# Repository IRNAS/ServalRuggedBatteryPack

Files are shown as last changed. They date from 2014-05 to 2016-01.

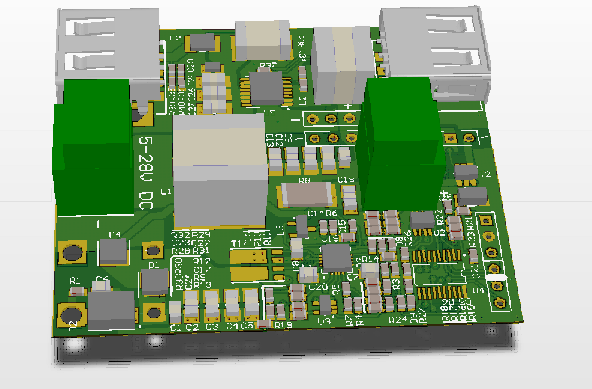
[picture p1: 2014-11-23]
electronics/V3/ServalRuggedBatteryPackV3.png

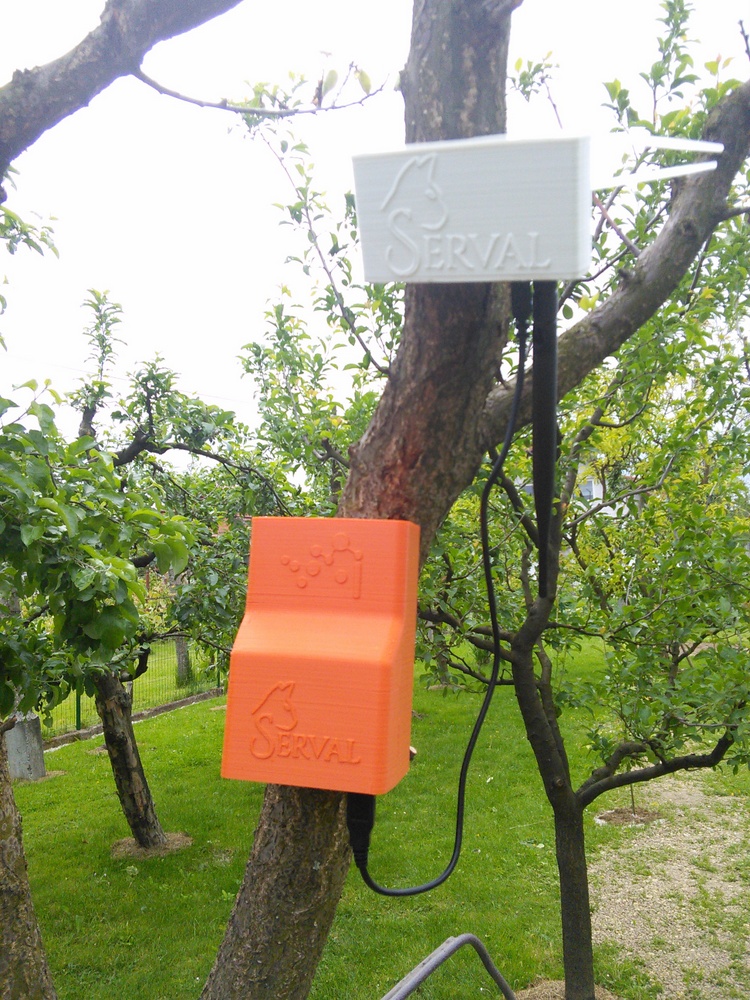
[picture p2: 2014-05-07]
photos/SRBP-Proto-4.jpg

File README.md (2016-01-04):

ServalRuggedBatteryPack
=======================

Serval Rugged Battery Pack is designed to be the universal battery supply system for wireless equipment in any situation. Let that be a rescue operation in New Zealand, every-day deployment in Africa or a remote location in Europe, all sharing the same lack of electrical power for communication equipment. Together with [Serval project](http://www.servalproject.org/)  we are creating an universal power solution for [Serval Mesh extender](http://developer.servalproject.org/dokuwiki/doku.php?id=content:meshextender:main_page)  and general use in community wireless networks.

## Early prototpe
Designed to house 2pcs LiFePO4 12Ah batteries and control electronics, developed in collaboration with [eCat](http://www.ecat.si/). It implements most of the described features, however supports only up to 1A charging current, making the usage of such a system with high capacity rather limited. Improvements are on the way.

Assembly parts:

ServalRuggedBatteryPack

Inside the 3D printed case:

ServalRuggedBatteryPack

In action with Serval Mesh Extender:

ServalRuggedBatteryPack
ServalRuggedBatteryPack

## Development goals
 * Supply power for the wireless device (5V USB or 12V)
 * Enough juice for days of operation
 * Charge it from just about anything
 * Make it hackable and reusable
 * Support real-time monitoring of the system
 
## Usage scenarios

### Serval Mesh Extender
[Serval Mesh extender](http://developer.servalproject.org/dokuwiki/doku.php?id=content:meshextender:main_page) is based on Openwrt devices, currently using Tp-Link MR3020 routers that on their own have a consumption of about 1W, [consumption data](http://developer.servalproject.org/dokuwiki/doku.php?id=content:meshextender:power_consumption_table). The external radio RFD900 peaks up to 1W as well. The desired operation on a single charge is multiple of days.

Maximum consumption of the setup is 2W, for 1 day operation that requires 48Wh.

### wlan slovenija network node
[wlan slovenija](https://wlan-si.net/)  is an open wireless mesh network in Slovenia, with some nodes deployed to temporary events without mains power available. Typical nodes are MR3020 with average consumption of 1W using 5V USB input and WR741ND with average consumption of 1W are 9-12V input.

Maximum consumption for the setup is 1W, more then 2 day of operation is desired.

## Battery technology and tests
The choice for safety, performance and price reasons is LiFePO4, however the design should be hackable to support Li-po as well.

Testing with two WH08Ah LiFePO4 cells in parallel powered MR3020 for 65h with average 230mA drain at battery voltage, average of 3.15V. The delivered power to the voltage regulator was about 47Wh, the actual device somewhere in the 42Wh range.

The upgrade to two 12Ah cells in parallel should deliver about 70Wh.

## Charging
The design goal is to enable fast charging of the battery pack allowed with LiFePO4 to reduce the time as much as possible.

Useful/available charging sources:
 * USB phone charger (5V/1A)
 * TP-Link wr741nd adapter (9V/600mA)
 * Car DC socket (12V/5A)
 * Motorcycle alternator (6V-12V/5A+)
 * Wind turbine (10W+) ???
 * DIY hack generator ?
 * [Hand crank generator](http://wiki.laptop.org/go/Peripherals/Hand_Crank) (15V/1.5A)
 * Solar cell (various)
 
The power quality of sources in the wild may vary, the input should have a wide range, up to 30V with protected to 400V, be AC/DC compatible, so wrong polarity can not be the issue. Charging should occur from any connected source, no matter what its capabilities are.

## Capacity
The device should operate from a single cell to simplify the design, enable easier operation cycles and avoid problems due to cell management. The capacity should depend on teh connected batteries, but generally should be in the range of 12Ah-48Ah, depending on the number of cells connected. This directly affect charging time.

## Monitoring
There should be a low-power processor on board that enables the collection of usage information, performs the battery protection function and enables extensive real-time information if so desired.

Parameters to be observed:
 * Input voltage
 * Output voltage
 * Battery voltage
 * Battery charge/discharge current
 * Temperature
 * Ambient light
 
The following features should be implemented in software:
 * Battery cycle count
 * Battery undervoltage protection
 * Load management
 * Communication with the external device
 
## Electronics
The brains should be MSP430G2452 compatible with [Energia environment](http://energia.nu), because of internal VCC measurement feature, temperature sensor, low power consumption nad affordable cost.

The charging part should ideally be built around BQ24650 IC from TI.

The output step-up part should be built with low-cost step-up devices. Pre-selectable config for 12V or 5V output.

Input connections:
 * micro/mini USB
 * DC jack
 * terminal block (push connect style, no screwdriver required)
 
Output connections:
 * 5V USB A
 * terminal block (push connect style, no screwdriver required)
 
 Allow units to be daisy-chained.
 
---

#### License

All our projects are as usefully open-source as possible.

Hardware including documentation is licensed under [CERN OHL v.1.2. license](http://www.ohwr.org/licenses/cern-ohl/v1.2)

Firmware and software originating from the project is licensed under [GNU GENERAL PUBLIC LICENSE v3](http://www.gnu.org/licenses/gpl-3.0.en.html).

Open data generated by our projects is licensed under [CC0](https://creativecommons.org/publicdomain/zero/1.0/legalcode).

All our websites and additional documentation are licensed under [Creative Commons Attribution-ShareAlike 4 .0 Unported License] (https://creativecommons.org/licenses/by-sa/4.0/legalcode).

What this means is that you can use hardware, firmware, software and documentation without paying a royalty and knowing that you'll be able to use your version forever. You are also free to make changes but if you share these changes then you have to do so on the same conditions that you enjoy.

Koruza, GoodEnoughCNC and IRNAS are all names and marks of Institut IRNAS Rače. 
You may use these names and terms only to attribute the appropriate entity as required by the Open Licences referred to above. You may not use them in any other way and in particular you may not use them to imply endorsement or authorization of any hardware that you design, make or sell.

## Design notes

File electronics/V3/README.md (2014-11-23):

Serval Rugged Battery Pack electronics V3 - pre-release
======================

ServalRuggedBatteryPack

This version of the battery pack improves on the previous design to allow for much faster charging, enabling the operation under more intermittent power supply conditions, such as winder periods when solar power is used.

Currently published version is for use in debugging process only and should not yet be used in real-world!

### System design
The system is designed in three major sections, Input and charging implementing LiFePO4 cell charging from 5-30V DC sources, Controller implementing the system monitoring functions and battery over-discharge protection with UART connectivity for measurement collection and Output stage with 5V regulated USB output for powering routers and other USB devices.

#### Input and charging
Charging is based on [TI BQ24650](http://www.ti.com/product/bq24650) Solar charge controller with MPPT functionality following the proposed reference design [bq24650EVM](http://www.ti.com/lit/ug/sluu444a/sluu444a.pdf) modified for LiFePO4 charging per [BQ24650 LiFePO4 manual](http://www.ti.com/lit/an/slua565/slua565.pdf). Additionally the MPPT set control is implemented via a digital potentiometer, so the Controller can dynamically change it based on the input voltage measurement. Current sense resistor is additionally monitored using (INA219)[http://www.ti.com/lit/ds/symlink/ina219.pdf], so the Controller can monitor charging and discharging accurately.

#### Controller
Controller is (MSP430G2553)[http://www.ti.com/product/msp430g2553] programmed in (Energia)[http://energia.nu] environment. It monitors the voltages and charging state and protects the battery from over-discharge, controls the output stage and an additional power channel for extra outputs.

#### Output stage
The output stage features (TPS61032)[http://www.ti.com/product/tps61032] high efficiency step-up regulator with 5V fixed output and two USB ports. One facing toward the inside of the device for powering a router for example within the case and an external one facing the connection side of the board with additional resistor dividers to allow charging of mobile devices.

### Known major bugs

Input and charging stage does not operate correctly. While all operating conditions are met and charging phase starts, the BQ24650 IC significantly heats up even with moderately low charging currents of about 500mA and after a few seconds falls into thermal shutdown. As external switching elements are used, there should be no power path going through the IC, however there must be one and the source of this error has not yet been discovered. All the operating conditions specified in the datasheet are met.

### Known minor bugs / ideas for improvement

High thermal conductivity of T1 pin 3 connected to P_GND may cause this pin not to be properly soldered during reflow, this must be kept in mind when assembling.

On rare occasion caused by human factor during measurements, both MOSFETs may turn on and cause a short circuit. While this is unlikely to occur during normal operation, the input fuse must be chosen such, that transistors are not damaged. A secondary fuse for the battery may also be a good idea.

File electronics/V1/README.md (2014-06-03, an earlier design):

Serval Rugged Battery Pack electronics V1
======================

ServalRuggedBatteryPack

This electronics design is a step in development and is not fully optimized for the end use-case. It features two input stages, a 5V input with a charge controller in parallel with a step-down stage in CV/CC mode for charging from voltage inputs of up to 30V.

Batteries used must be single cell LiFePO4.

The controller stage features a MSP430G2452 microcontroller and an INA219 current measurement IC to monitor the battery state and perform battery protection functions, controlling the load via a MOSFET. The two 4 pin output block enable an UART connection to the outside world and programming.

Load output voltage is set resistor network with jumper selection for 5V or 12V output, mind using the appropriate output connector.

### Known bugs
 
C16 must have sufficiently small ESR, add a capacitor in parallel if insufficient charge current is observed.

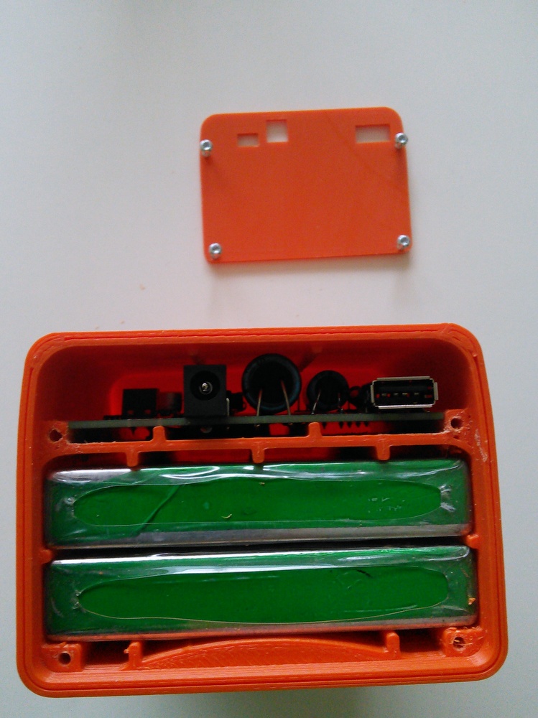
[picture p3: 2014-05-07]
photos/SRBP-Proto-3.jpg

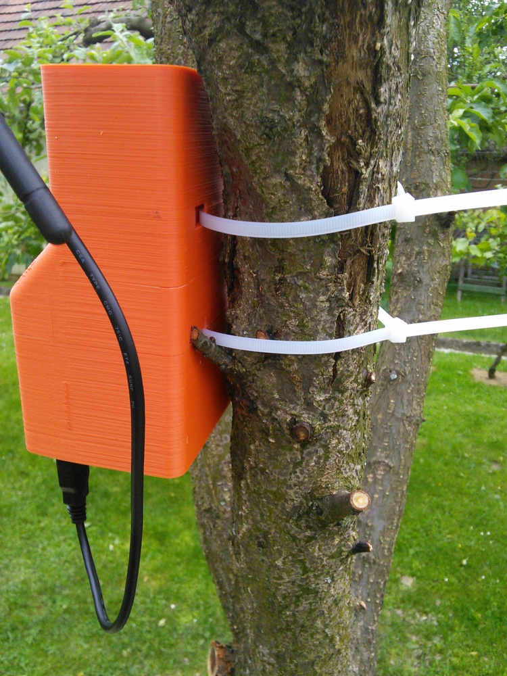
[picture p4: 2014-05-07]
photos/SRBP-Proto-1.jpg

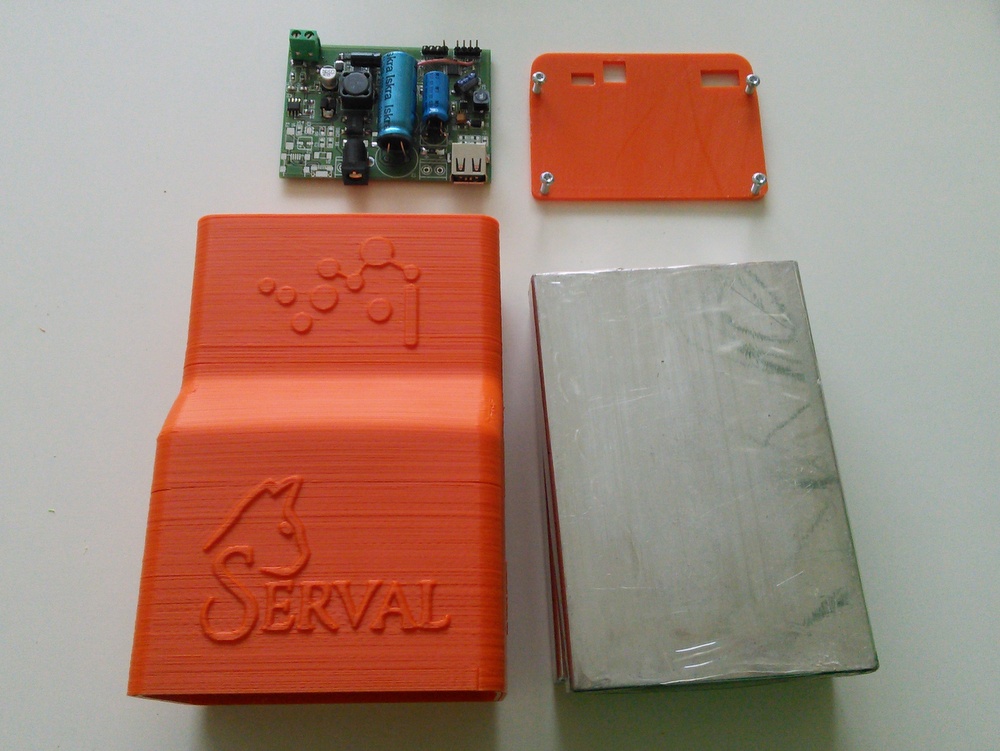
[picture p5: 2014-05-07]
photos/SRBP-Proto-2.jpg

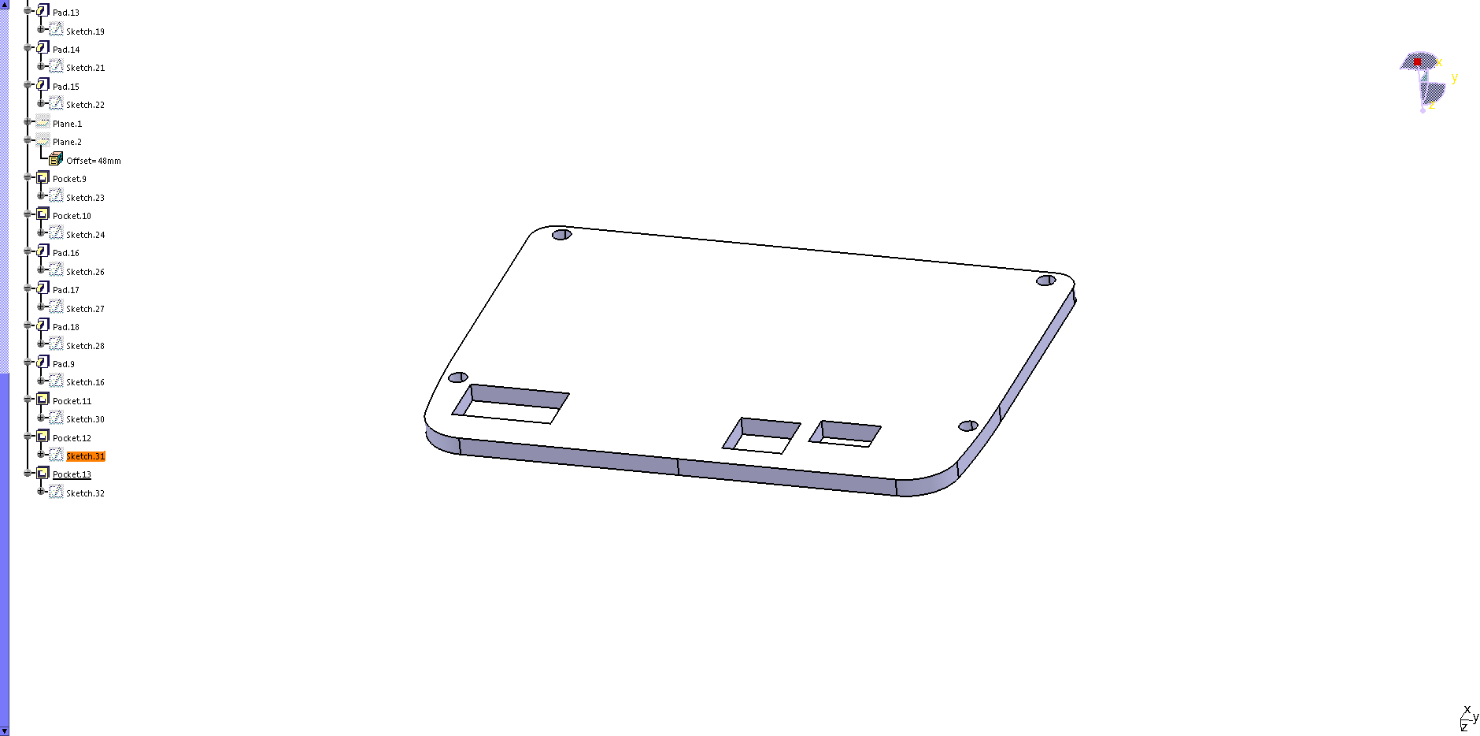
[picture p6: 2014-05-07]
enclosure/capture3.png

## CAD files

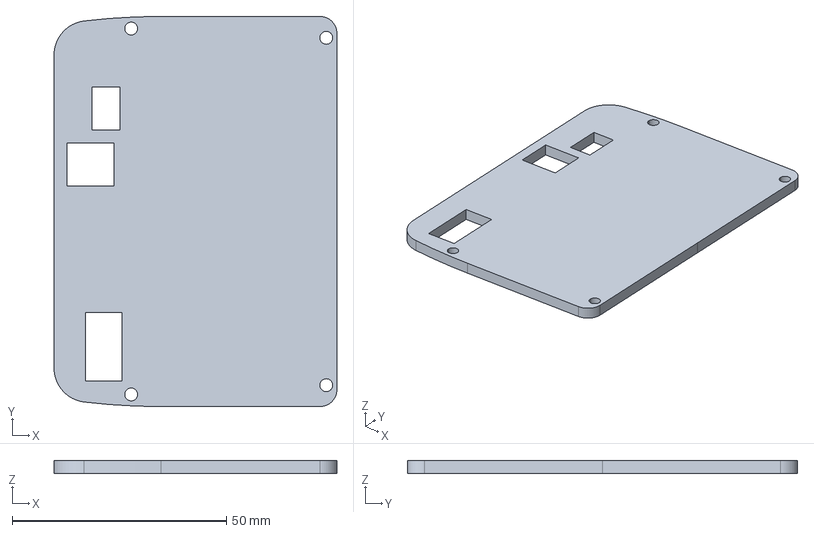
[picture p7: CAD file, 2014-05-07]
enclosure/cover.stp
66.0 x 91.0 x 3.00 mm

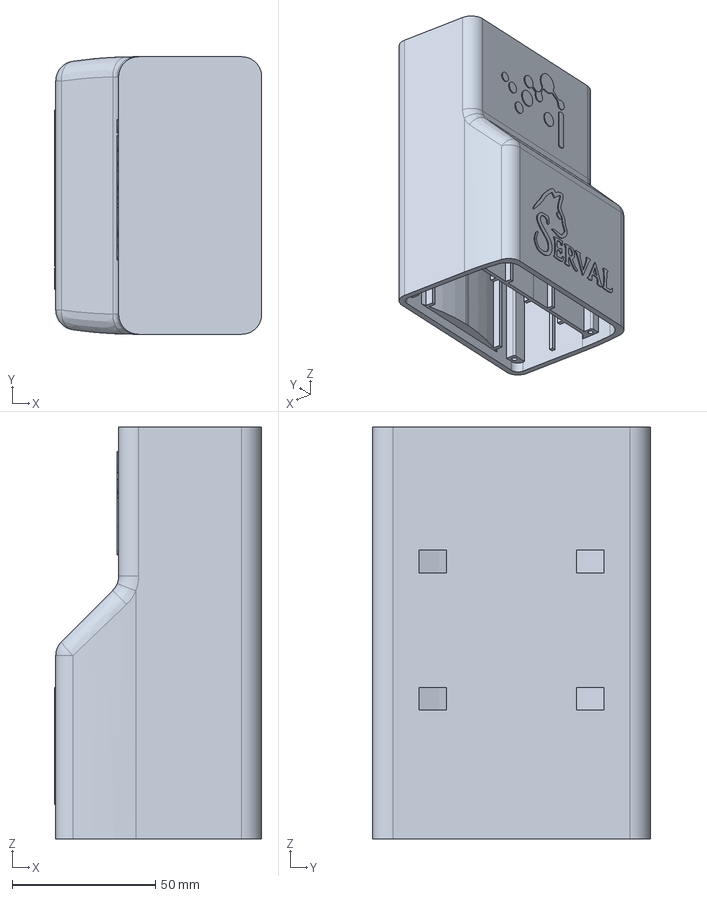
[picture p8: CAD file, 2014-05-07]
enclosure/enclosure.stp
72.5 x 97.0 x 144.0 mm

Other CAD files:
enclosure/cover.stl
enclosure/enclosure.stl

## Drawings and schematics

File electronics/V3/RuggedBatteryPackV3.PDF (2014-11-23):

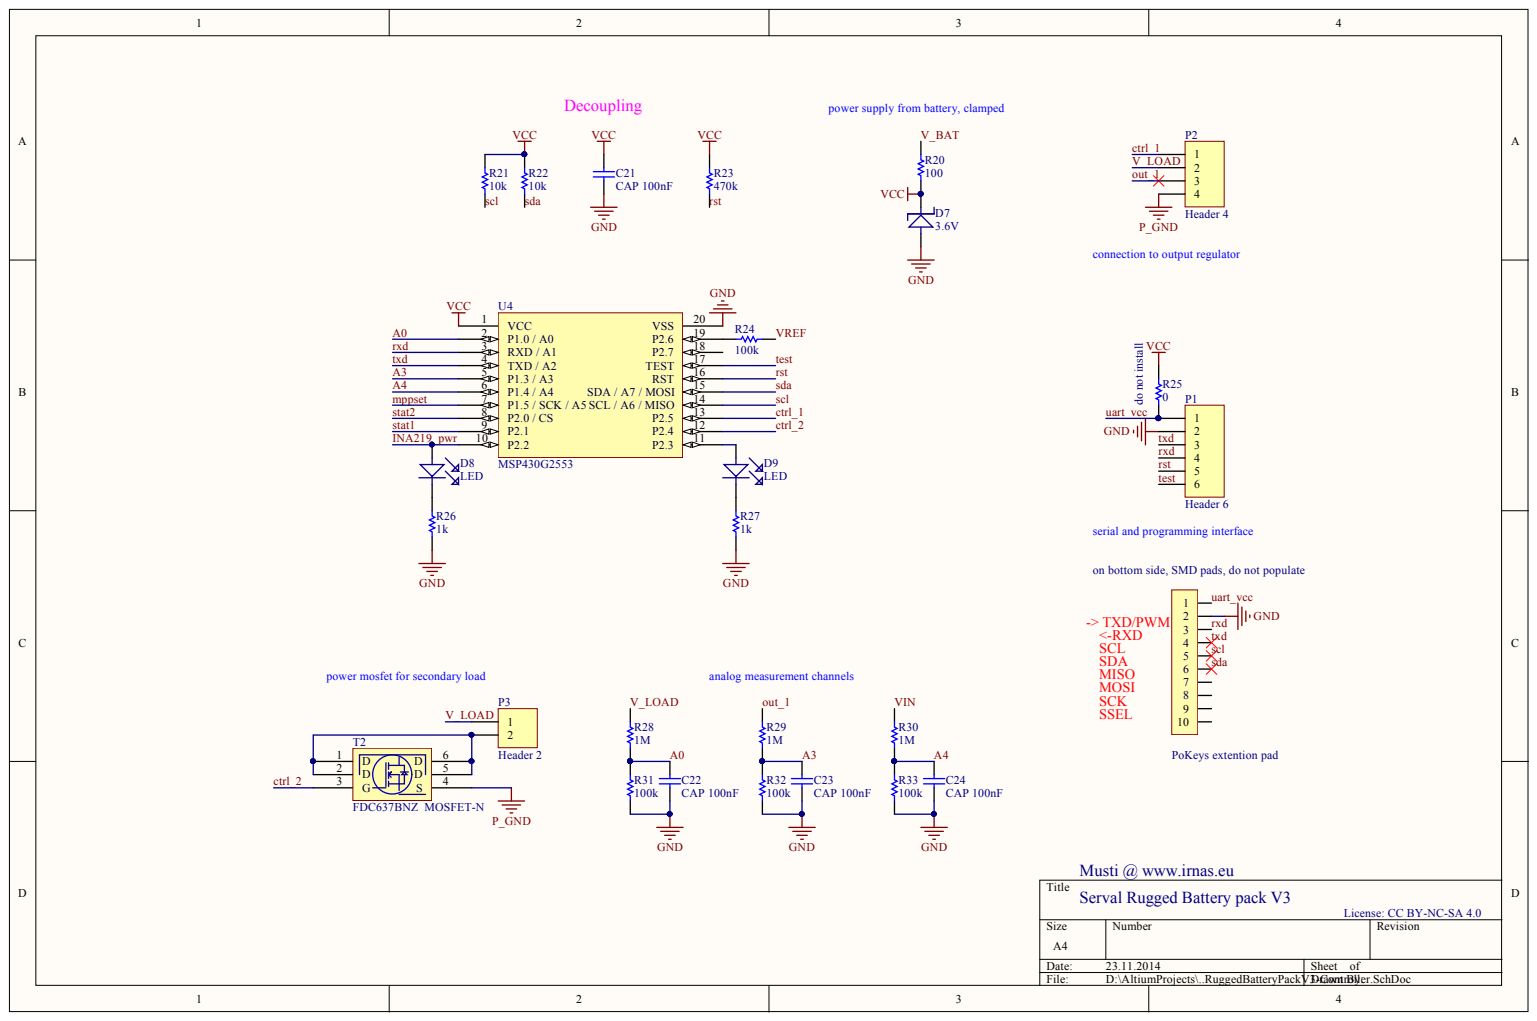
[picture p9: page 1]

-> TXD/PWM <-RXD SCL SDA MISO MOSI SCK SSEL

3D-Co rawnnt By roll

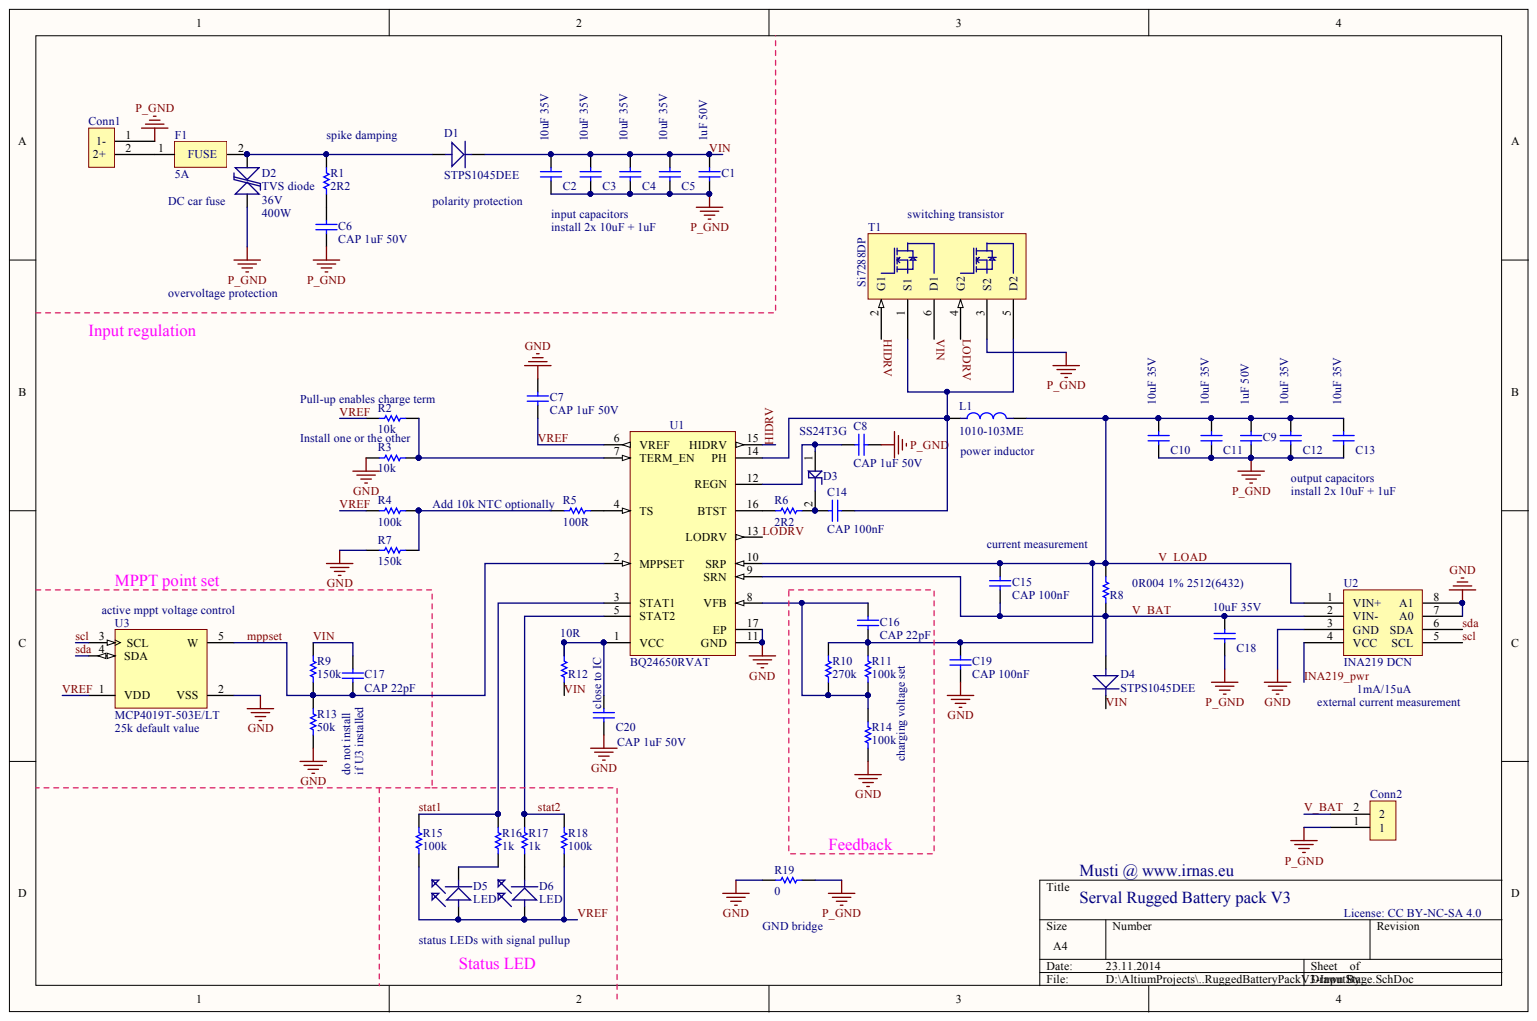
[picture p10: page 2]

Install one or the other

stat1 | stat2

Musti @ www.irnas.eu
Title
Serval Rugged Battery pack V3

License: CC BY-NC-SA 4.0

status LEDs with signal pullup
Status LED

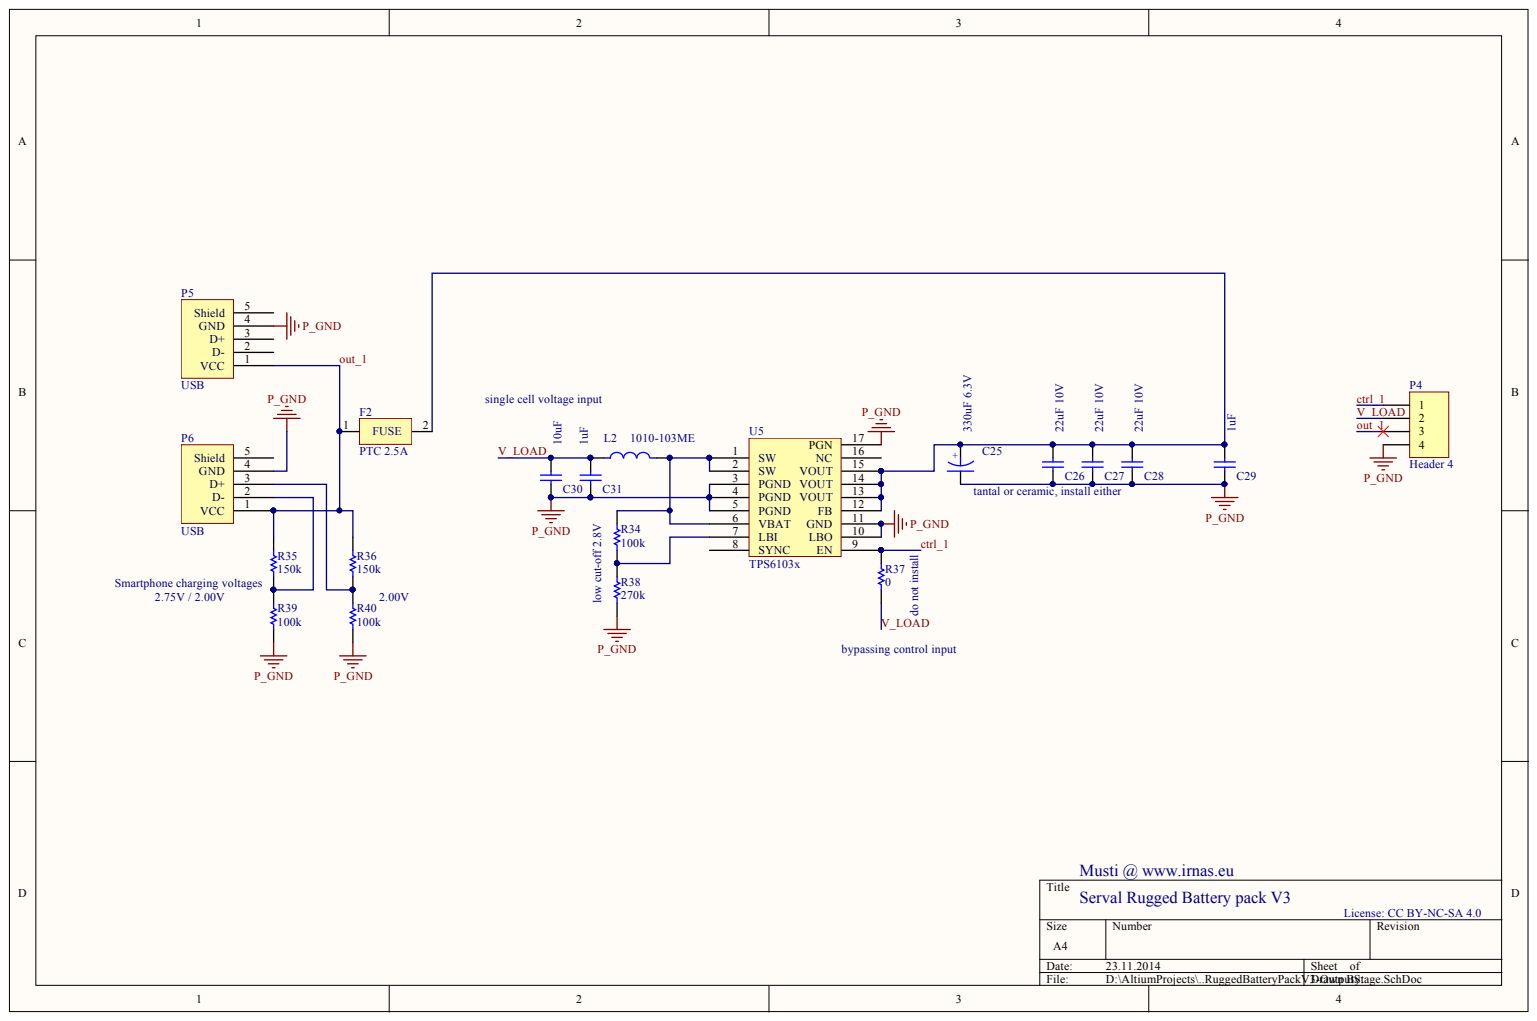
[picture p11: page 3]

3D-Orawutnp By utSt:age.Sch

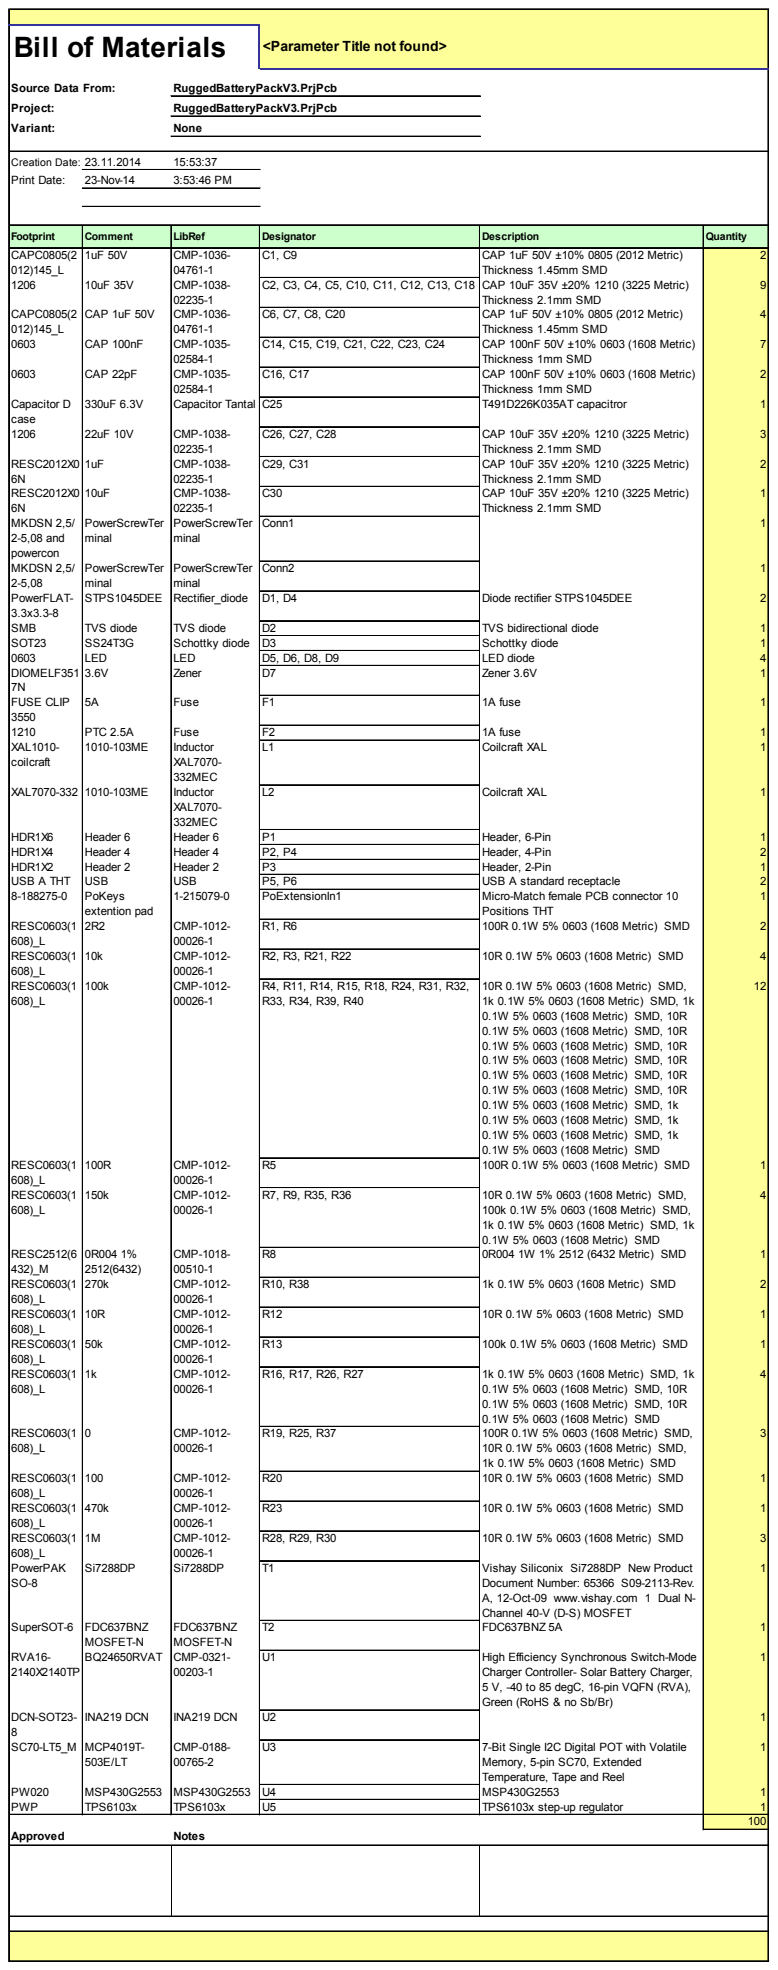
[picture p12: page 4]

Footprint | Comment | LibRef | Designator | Description | Quantity

Conn1 | 1

Conn2 | 1

Document Number: 65366 S09-2113-Rev.
A, 12-Oct-09 www.vishay.com 1 Dual N-
Channel 40-V (D-S) MOSFET

Charger Controller- Solar Battery Charger,
5 V, -40 to 85 degC, 16-pin VQFN (RVA),
Green (RoHS & no Sb/Br)

Memory, 5-pin SC70, Extended
Temperature, Tape and Reel

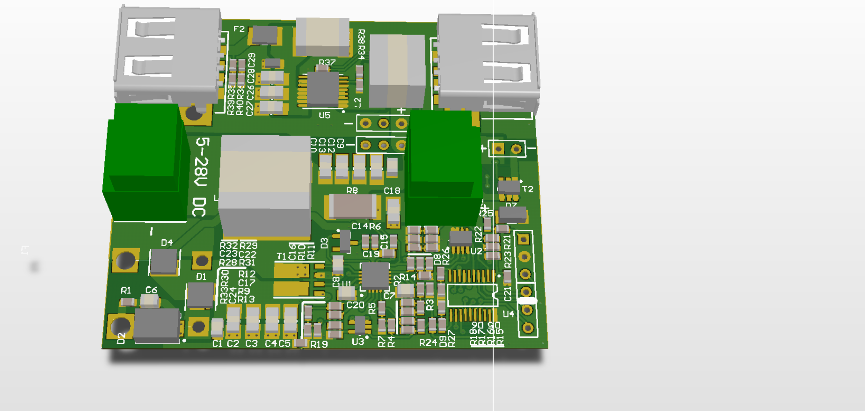
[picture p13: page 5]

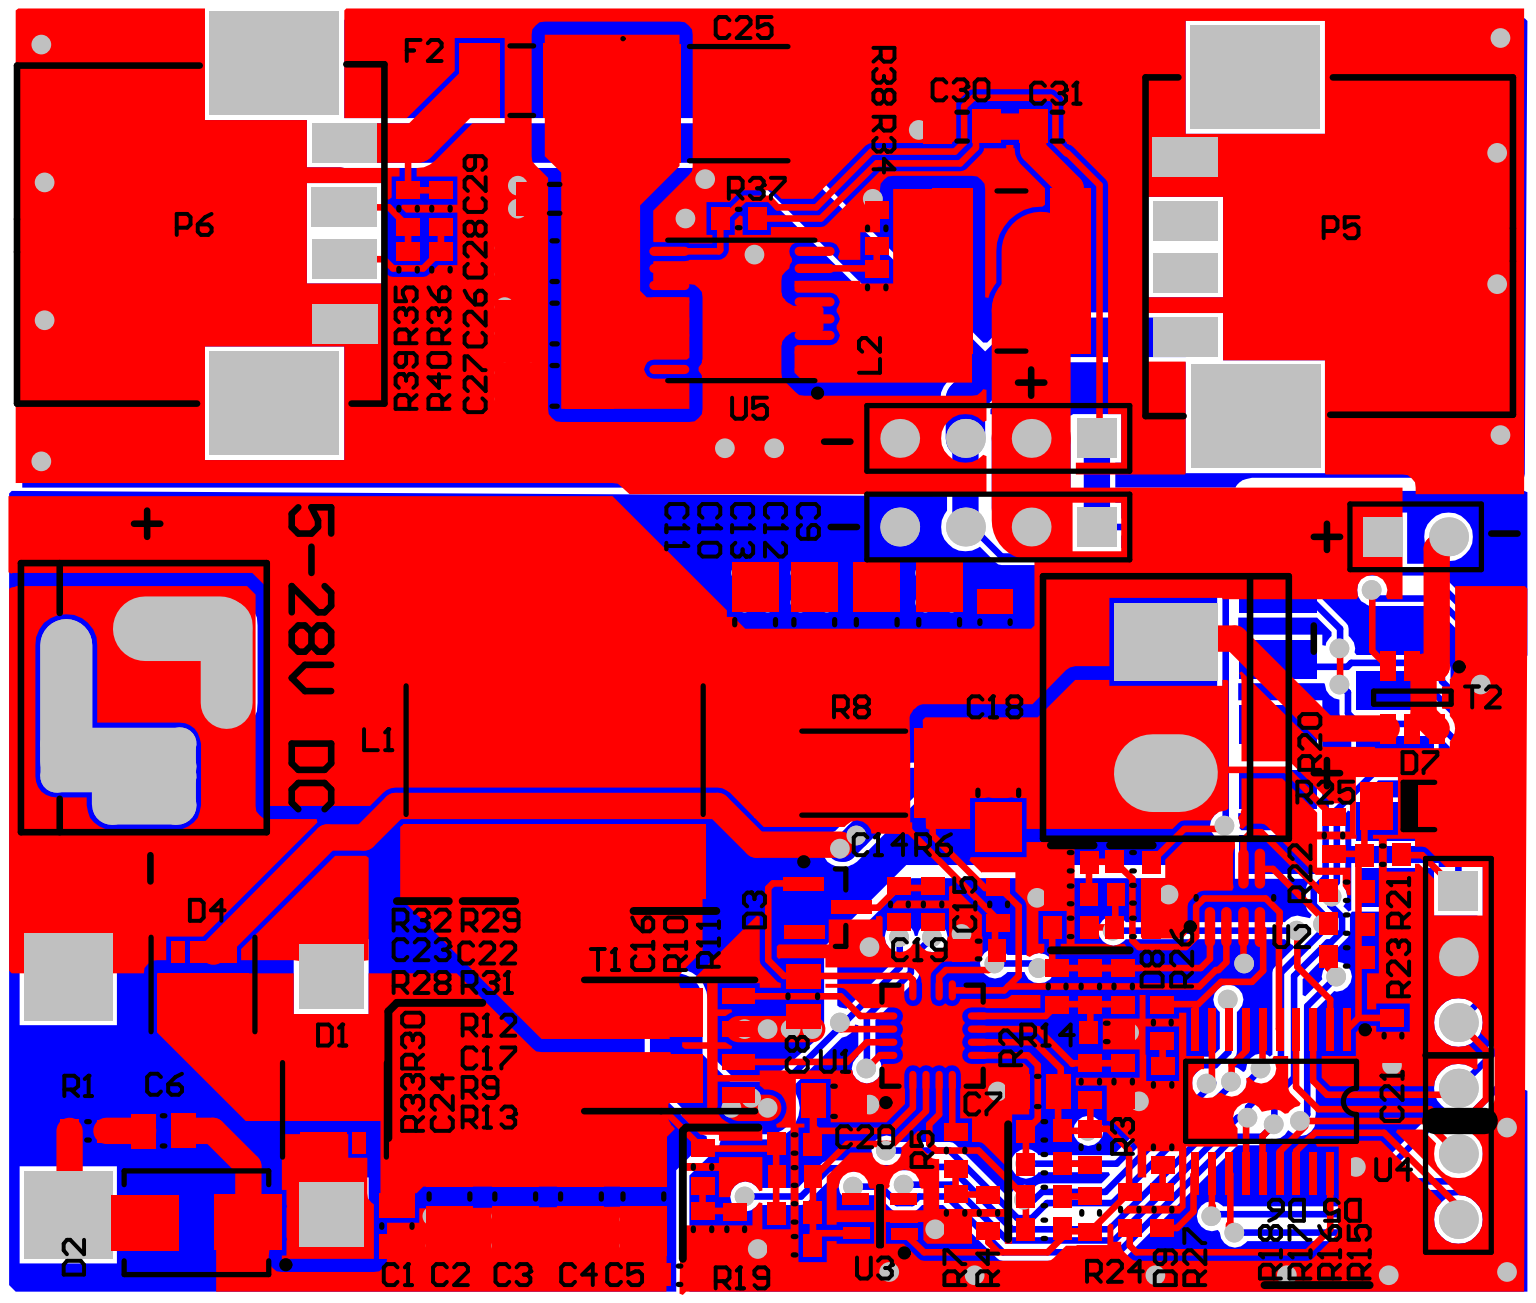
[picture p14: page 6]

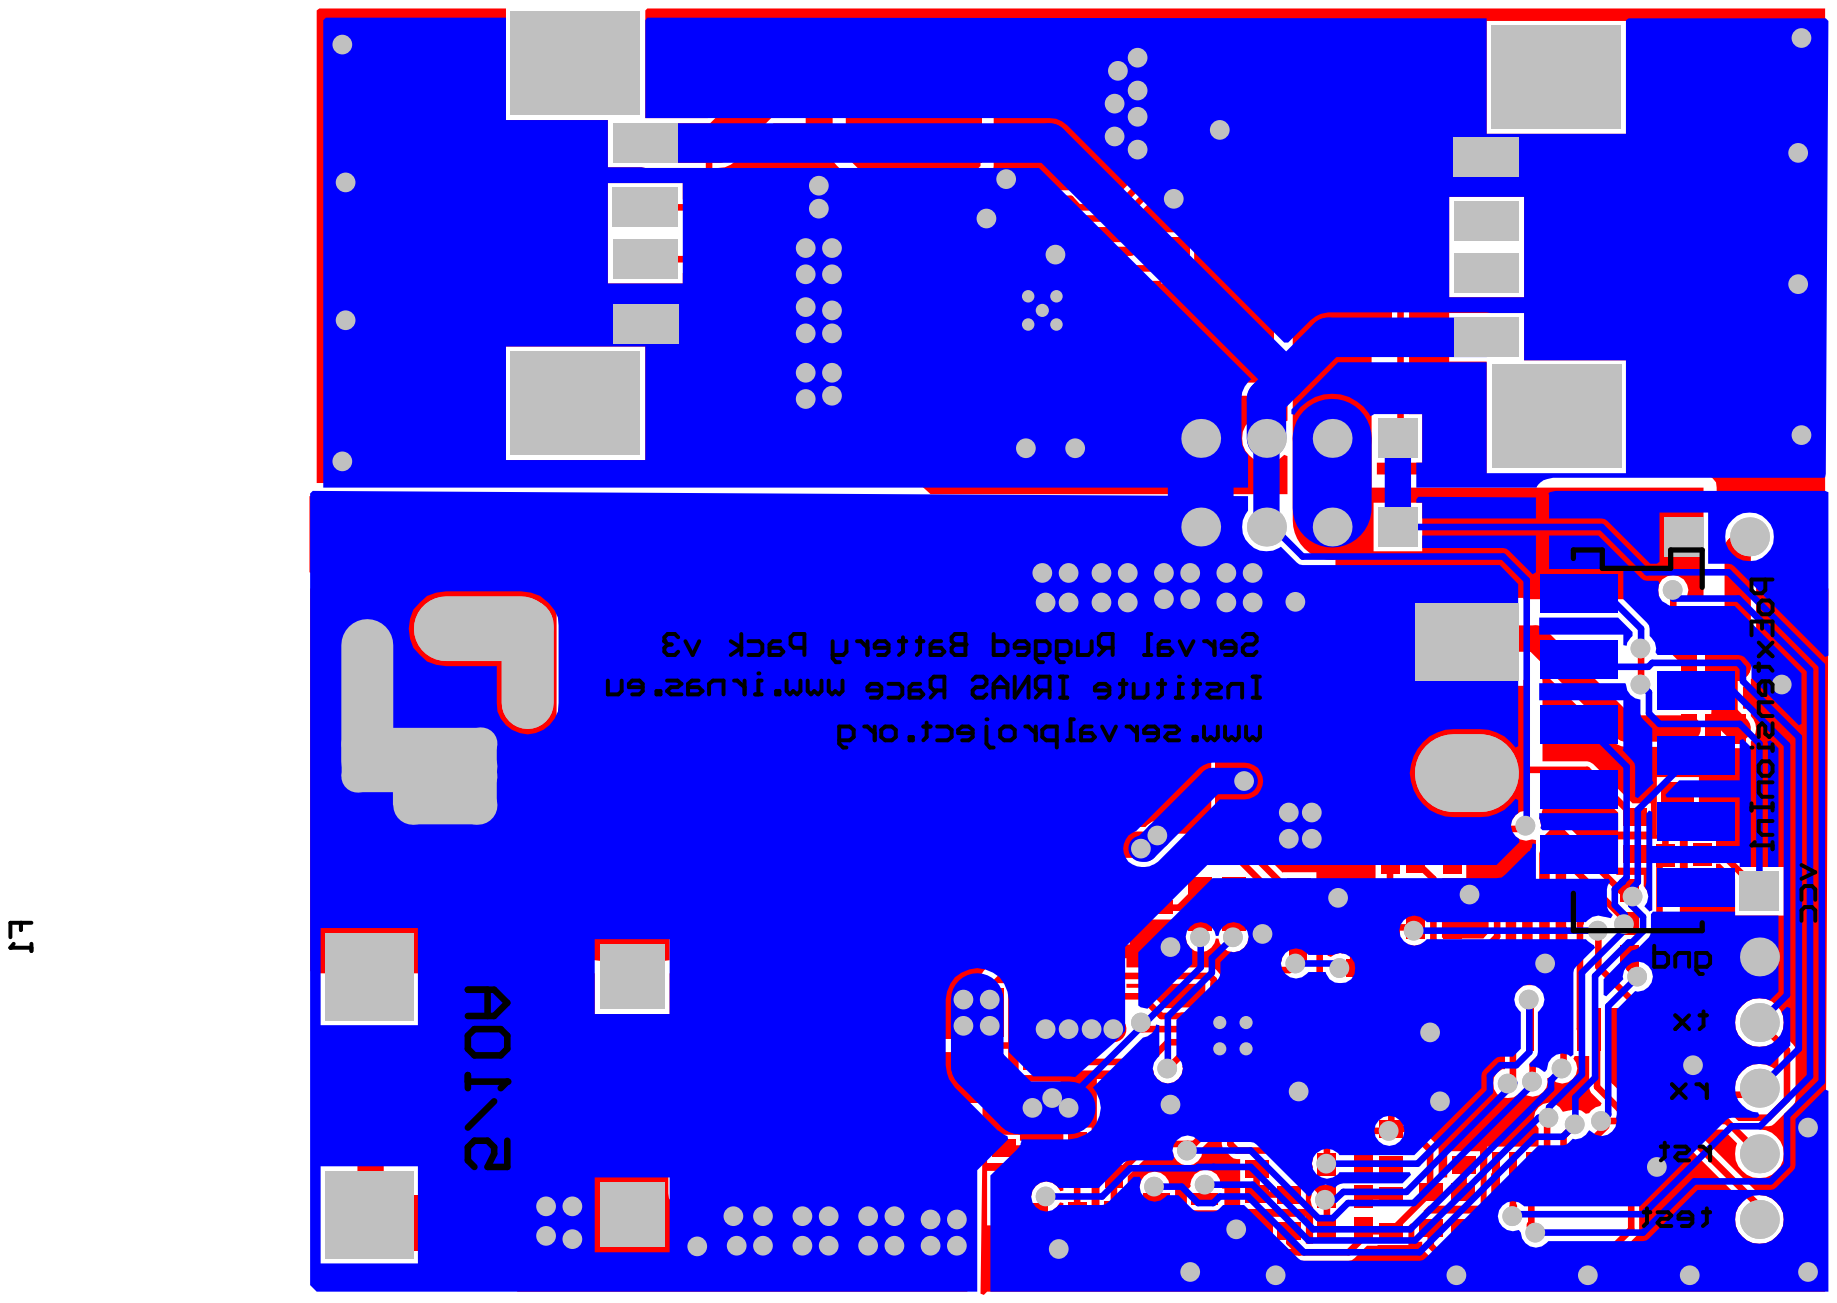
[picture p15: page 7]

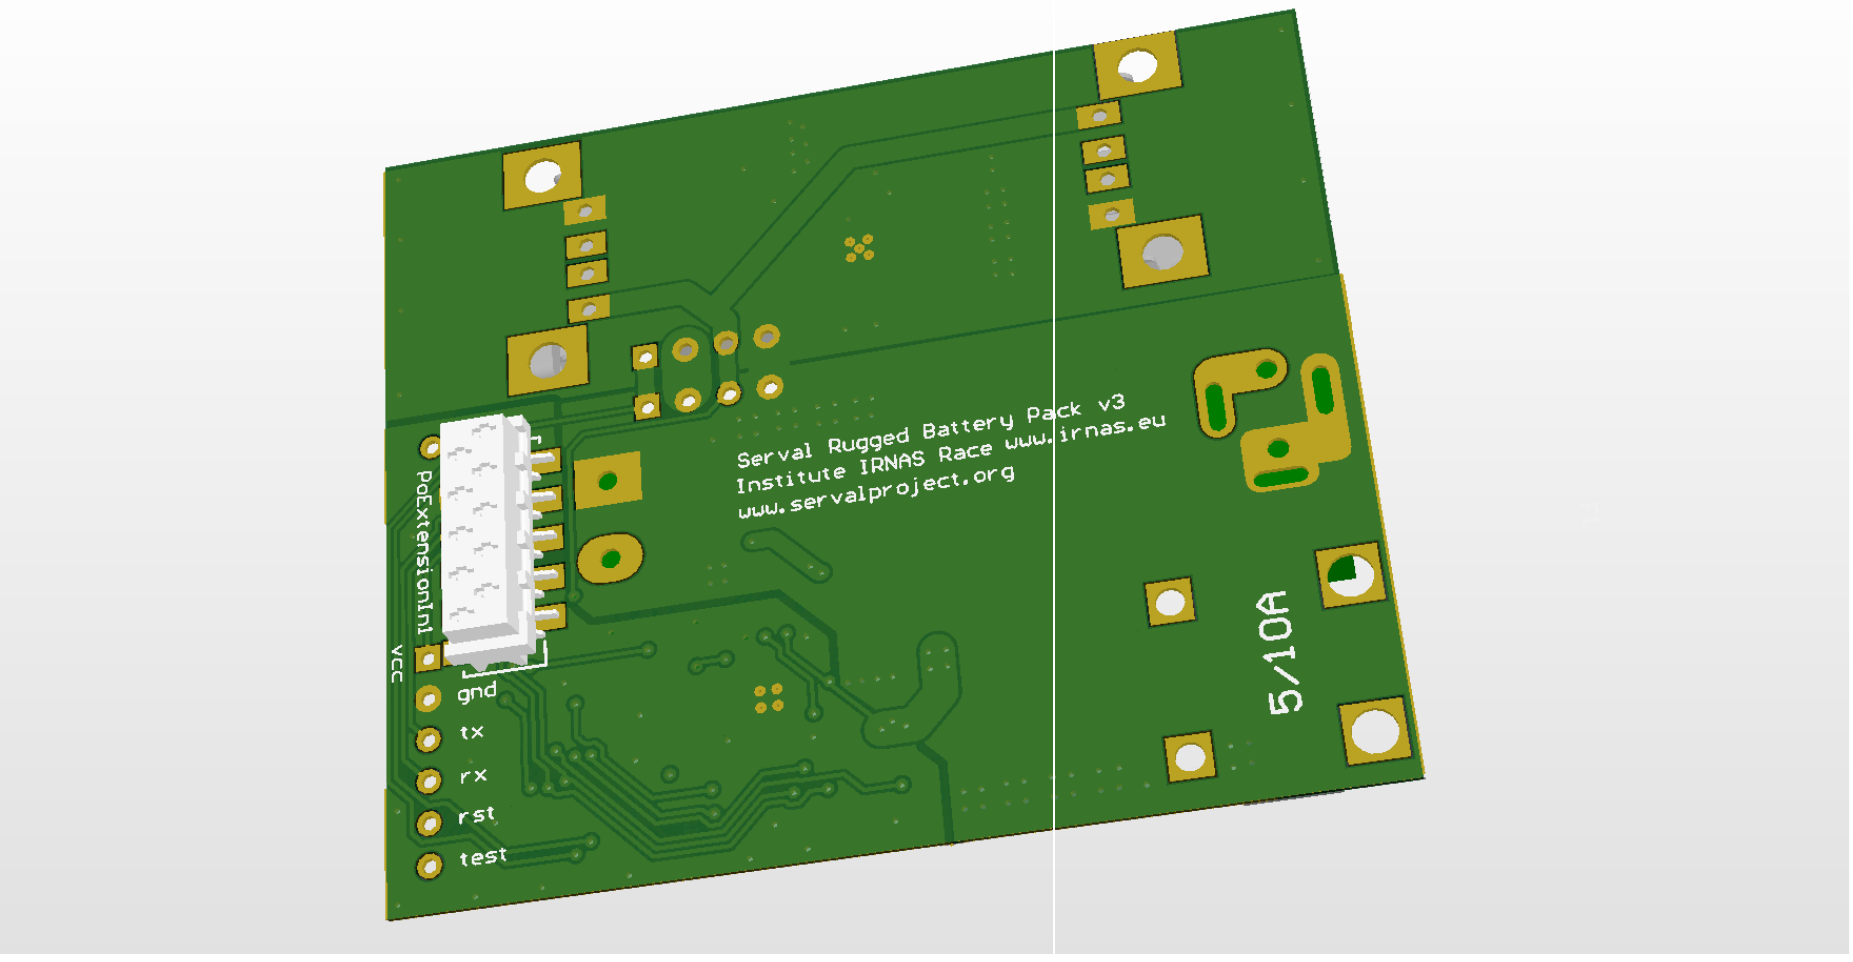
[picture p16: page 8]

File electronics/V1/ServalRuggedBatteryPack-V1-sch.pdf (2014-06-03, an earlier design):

# www.servalproject.org

# Serval Rugged Battery Pack v1

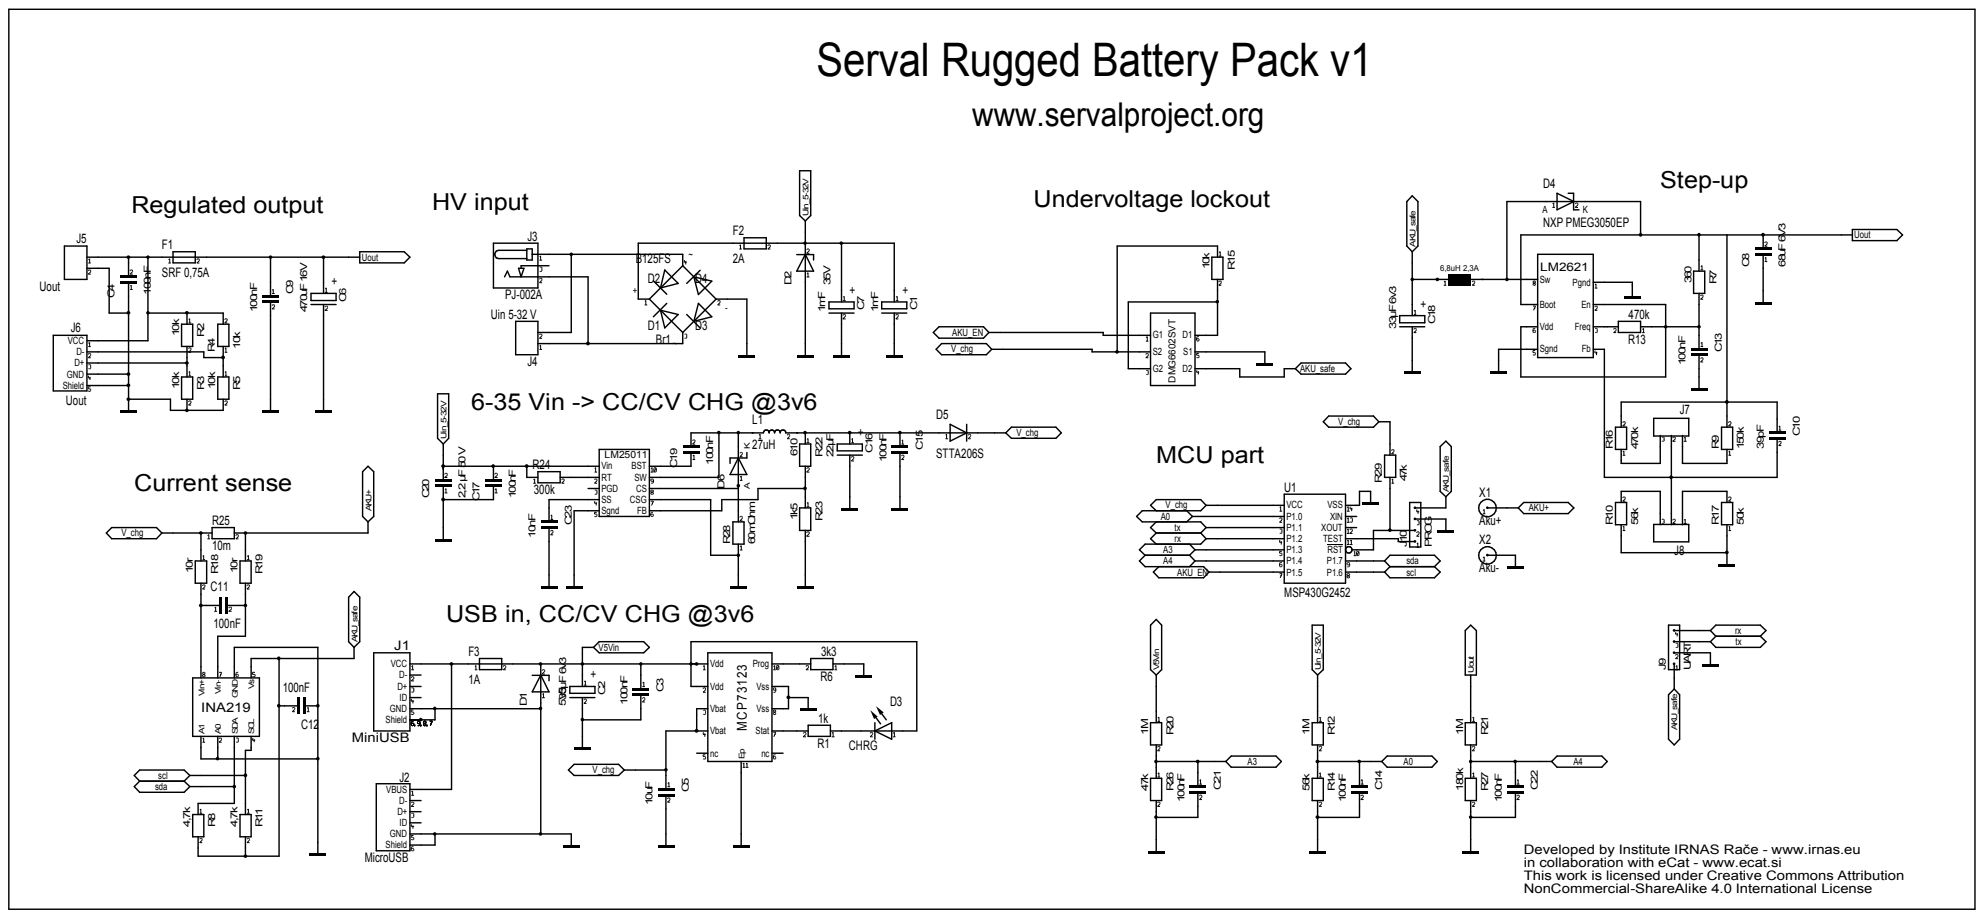
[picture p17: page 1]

USB in, CC/CV CHG @3v6

Developed by Institute IRNAS Rače - www.irnas.eu
in collaboration with eCat - www.ecat.si
This work is licensed under Creative Commons Attribution
NonCommercial-ShareAlike 4.0 International License

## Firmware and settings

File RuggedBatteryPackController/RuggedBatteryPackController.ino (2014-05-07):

/*
Copyright 2013 Institute IRNAS Race - Luka Mustafa - Musti, musti@irnas.eu

ServalRuggedBatteryPack is to be used with Energia environment and MSP430G2452

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
*/

#include <Wire.h>
//The library needs to be modified if it does not fit the MCU by removing functions containing float. Calibration constant in the library needs to be modified.
#include <Adafruit_INA219.h>

//Pinout
#define IN_A_INPUT12 A0
//divider 1M/56k, max value with 2.5Vref = 47.123V
#define IN_A_INPUT5 A3
//divider 1M/470k, max value with 2.5Vref = 7.812V
#define IN_A_OUTPUT A4
//divider 1M/180k, max value with 2.5Vref = 16.389V
#define IN_A_INTERNAL 11

#define OUT_CONTROL P1_5
#define OUT_LED P2_7

#define VOLTAGE_LOW 2700
#define VOLTAGE_HIGH 3000

boolean LOAD_CTRL=LOW;

int battery_voltage=0;

Adafruit_INA219 ina219;

void setup()
{  
  Serial.begin(9600);
  
  pinMode(IN_A_INPUT12,INPUT);
  pinMode(IN_A_INPUT5,INPUT);
  pinMode(IN_A_OUTPUT,INPUT);
  pinMode(OUT_CONTROL,OUTPUT);
  digitalWrite(OUT_CONTROL,HIGH);
  pinMode(OUT_LED,OUTPUT);
  digitalWrite(OUT_LED,HIGH);
  analogReference(INTERNAL2V5);
  
  ina219.begin();
  //modify I2C to be non-blocking
  
}

int GETfunctions[5]={(int)nodewatcher};
int SETfunctions[1]={(int)testSET};

//***************************************************************
// Functions for reading/writing and sensor communication

//**************************

void nodewatcher(){
  Serial.println("#START");
  
  int16_t shuntvoltage = 0;//ina219.getShuntVoltage_raw();
  int16_t busvoltage = 0;//ina219.getBusVoltage_raw();
  int16_t current_mA = 0;//ina219.getCurrent_raw();  
  
  if(LOAD_CTRL){
    shuntvoltage = ina219.getShuntVoltage_raw()/100;
    busvoltage = ina219.getBusVoltage_raw();
    current_mA = ina219.getCurrent_raw()/3;
  }
  
  battery_voltage = map(analogRead(IN_A_INTERNAL),0,1023,0,5000);
  int input12_voltage = map(analogRead(IN_A_INPUT12),0,1023,0,47123);
  int input5_voltage = map(analogRead(IN_A_INPUT5),0,1023,0,7812);
  int output_voltage = map(analogRead(IN_A_OUTPUT),0,1023,0,16389);
  
  Serial.print("environment.sensor0.temp:");
  Serial.println(battery_voltage,DEC);
  Serial.println("environment.sensor0.serial: Battery (mV)");
  
  Serial.print("environment.sensor1.temp:");
  Serial.println(input12_voltage,DEC);
  Serial.println("environment.sensor1.serial: HV input (mV)");
  
  Serial.print("environment.sensor2.temp:");
  Serial.println(input5_voltage,DEC);
  Serial.println("environment.sensor2.serial: USB input (mV)");
  
  Serial.print("environment.sensor3.temp:");
  Serial.println(output_voltage,DEC);
  Serial.println("environment.sensor3.serial: Output (mV)");
  
  Serial.print("environment.sensor4.temp:");
  Serial.println(shuntvoltage,DEC);
  Serial.println("environment.sensor4.serial: Shunt voltage (mV)");
  
  Serial.print("environment.sensor5.temp:");
  Serial.println(busvoltage,DEC);
  Serial.println("environment.sensor5.serial: Bus voltage (mV)");
  
  Serial.print("environment.sensor6.temp:");
  Serial.println(current_mA,DEC);
  Serial.println("environment.sensor6.serial: Current (mA)");
  

  Serial.println("#STOP");
}

void testSET(int data){
  Serial.println("#START");
  Serial.println("Test");
  Serial.println("#STOP");
}


void loop()
{
  //battery protection
  battery_voltage = map(analogRead(IN_A_INTERNAL),0,1023,0,5000);
  if (battery_voltage<VOLTAGE_LOW && LOAD_CTRL==HIGH){
    LOAD_CTRL=LOW;
  }
  if (battery_voltage>VOLTAGE_HIGH && LOAD_CTRL==LOW){
    LOAD_CTRL=HIGH;
  }
  digitalWrite(OUT_CONTROL,LOAD_CTRL);  
  
  // handles incoming UART commands
  // wait for at least 7 characters:
  while (Serial.available() > 3) {
    int x = 0;
    int v = 0;
    // Check for "ACOM /" string
    if(Serial.find("A ")){
      // parse command number after /
      x = Serial.parseInt(); 
      //if termianted, call GET
      if (Serial.read() == '\n'){
        // call GET function
        ((void (*)()) GETfunctions[x])();
      }
      //if nto terminated, read value argument and call SET
      else{
        v = Serial.parseInt();
        ((void (*)(int)) SETfunctions[x])(v); 
      }
      //more arguments can be supported in the same manner
    }
  }
}

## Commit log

2014-05-07 Initial commit.
    Adding the prototype.
    [cover.stl, cover.stp, enclosure.stl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]
2014-06-03 Added electronics V1.
    Electronics schematic and board with gerber files.

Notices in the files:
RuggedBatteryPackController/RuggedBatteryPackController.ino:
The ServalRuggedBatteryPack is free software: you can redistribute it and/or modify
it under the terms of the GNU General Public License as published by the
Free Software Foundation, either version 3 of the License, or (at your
